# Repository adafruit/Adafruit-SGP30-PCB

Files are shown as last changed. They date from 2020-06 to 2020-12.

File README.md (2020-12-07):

## Adafruit SGP30 Air Quality Sensor PCB

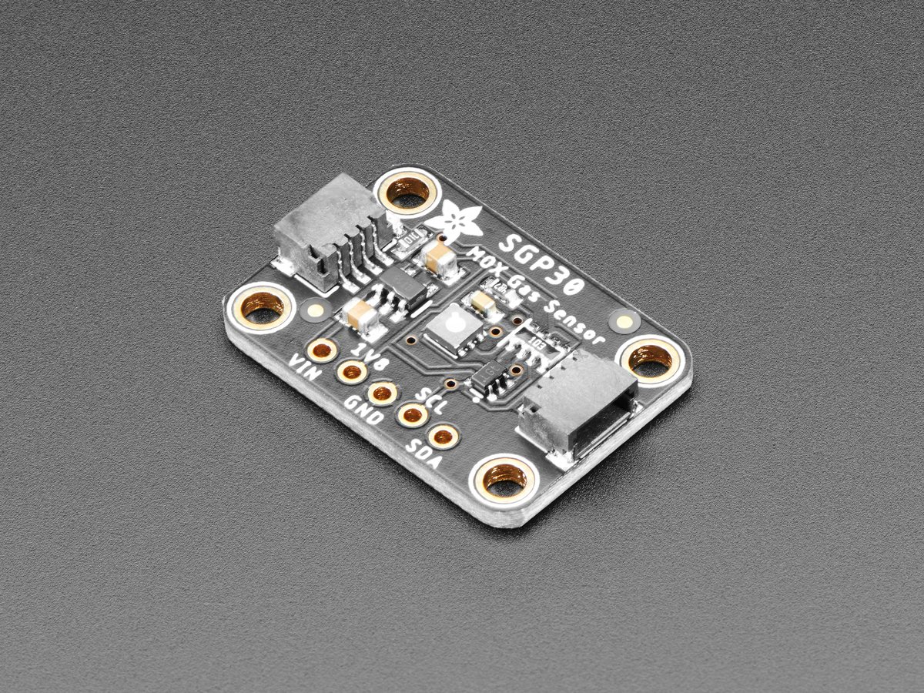
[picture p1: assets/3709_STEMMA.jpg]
<a href="http://www.adafruit.com/products/3709"><br/>
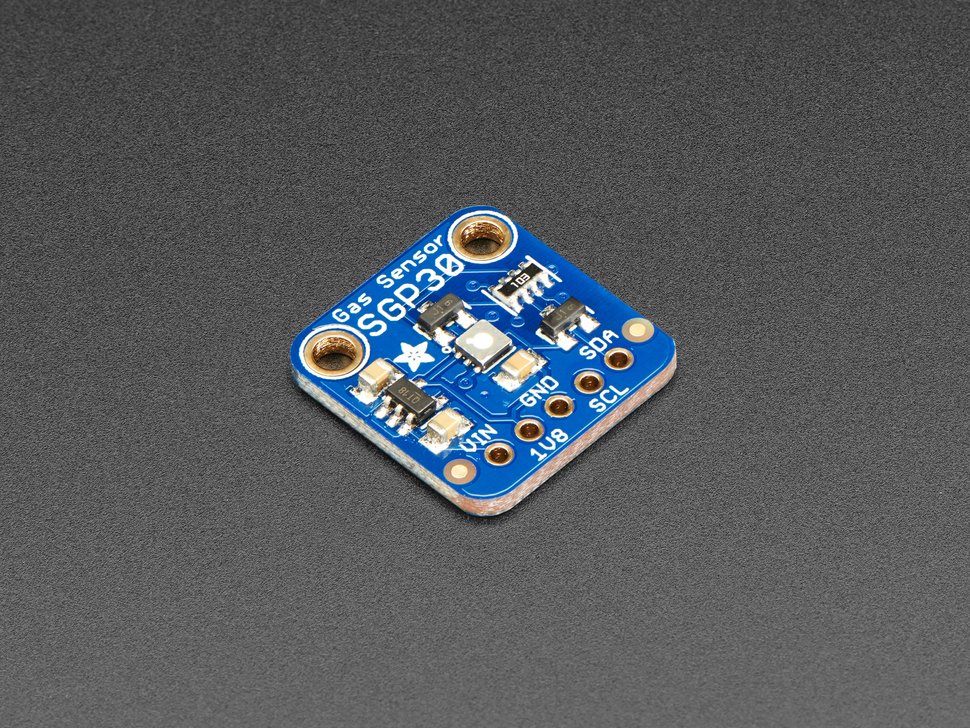
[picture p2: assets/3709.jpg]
<a href="http://www.adafruit.com/products/3709"><br/>
Click here to purchase one from the Adafruit shop</a>

PCB files for the Adafruit SGP30 Air Quality Sensor. 

Format is EagleCAD schematic and board layout
* https://www.adafruit.com/product/3709

### Description

Breathe easy with the SGP30 Multi-Pixel Gas Sensor, a fully integrated MOX gas sensor. This is a very fine air quality sensor from the sensor experts at Sensirion, with I2C interfacing and fully calibrated output signals with a typical accuracy of 15% within measured values. The SGP combines multiple metal-oxide sensing elements on one chip to provide more detailed air quality signals.

This is a gas sensor that can detect a wide range of Volatile Organic Compounds (VOCs) and H2 and is intended for indoor air quality monitoring. When connected to your microcontroller (running our library code) it will return a Total Volatile Organic Compound (TVOC) reading and an equivalent carbon dioxide reading (eCO2) over I2C.

The SGP30 has a 'standard' hot-plate MOX sensor, as well as a small microcontroller that controls power to the plate, reads the analog voltage, tracks the baseline calibration, calculates TVOC and eCO2 values, and provides an I2C interface to read from. Unlike the CCS811, this sensor does not require I2C clock stretching.

This part will measure eCO2 (equivalent calculated carbon-dioxide) concentration within a range of 400 to 60,000 parts per million (ppm), and TVOC (Total Volatile Organic Compound) concentration within a range of 0 to 60,000 parts per billion (ppb).

Please note, this sensor, like all VOC/gas sensors, has variability and to get precise measurements you will want to calibrate it against known sources! That said, for general environmental sensors, it will give you a good idea of trends and comparison. The SGP30 does have built in calibration capabilities, note that eCO2 is calculated based on H2 concentration, it is not a 'true' CO2 sensor for laboratory use.

Another nice element to this sensor is the ability to set humidity compensation for better accuracy. An external humidity sensor is required and then the RH% is written over I2C to the sensor, so it can better calculate the TVOC/eCO2 values.

Nice sensor right? So we made it easy for you to get right into your next project. The surface-mount sensor is soldered onto a custom made PCB in the STEMMA QT form factor, making them easy to interface with. The STEMMA QT connectors on either side are compatible with the SparkFun Qwiic I2C connectors. This allows you to make solderless connections between your development board and the SGP30 or to chain it with a wide range of other sensors and accessories using a compatible cable.

We’ve of course broken out all the pins to standard headers and added a 1.8V voltage regulator and level shifting so allow you to use it with either 3.3V or 5V systems such as the Raspberry Pi, or Metro M4 or Arduino Uno.

### License

Adafruit invests time and resources providing this open source design, please support Adafruit and open-source hardware by purchasing products from [Adafruit](https://www.adafruit.com)!

Designed by Kevin (KTOWN) Townsend for Adafruit Industries.

Creative Commons Attribution/Share-Alike, all text above must be included in any redistribution. 
See license.txt for additional details.

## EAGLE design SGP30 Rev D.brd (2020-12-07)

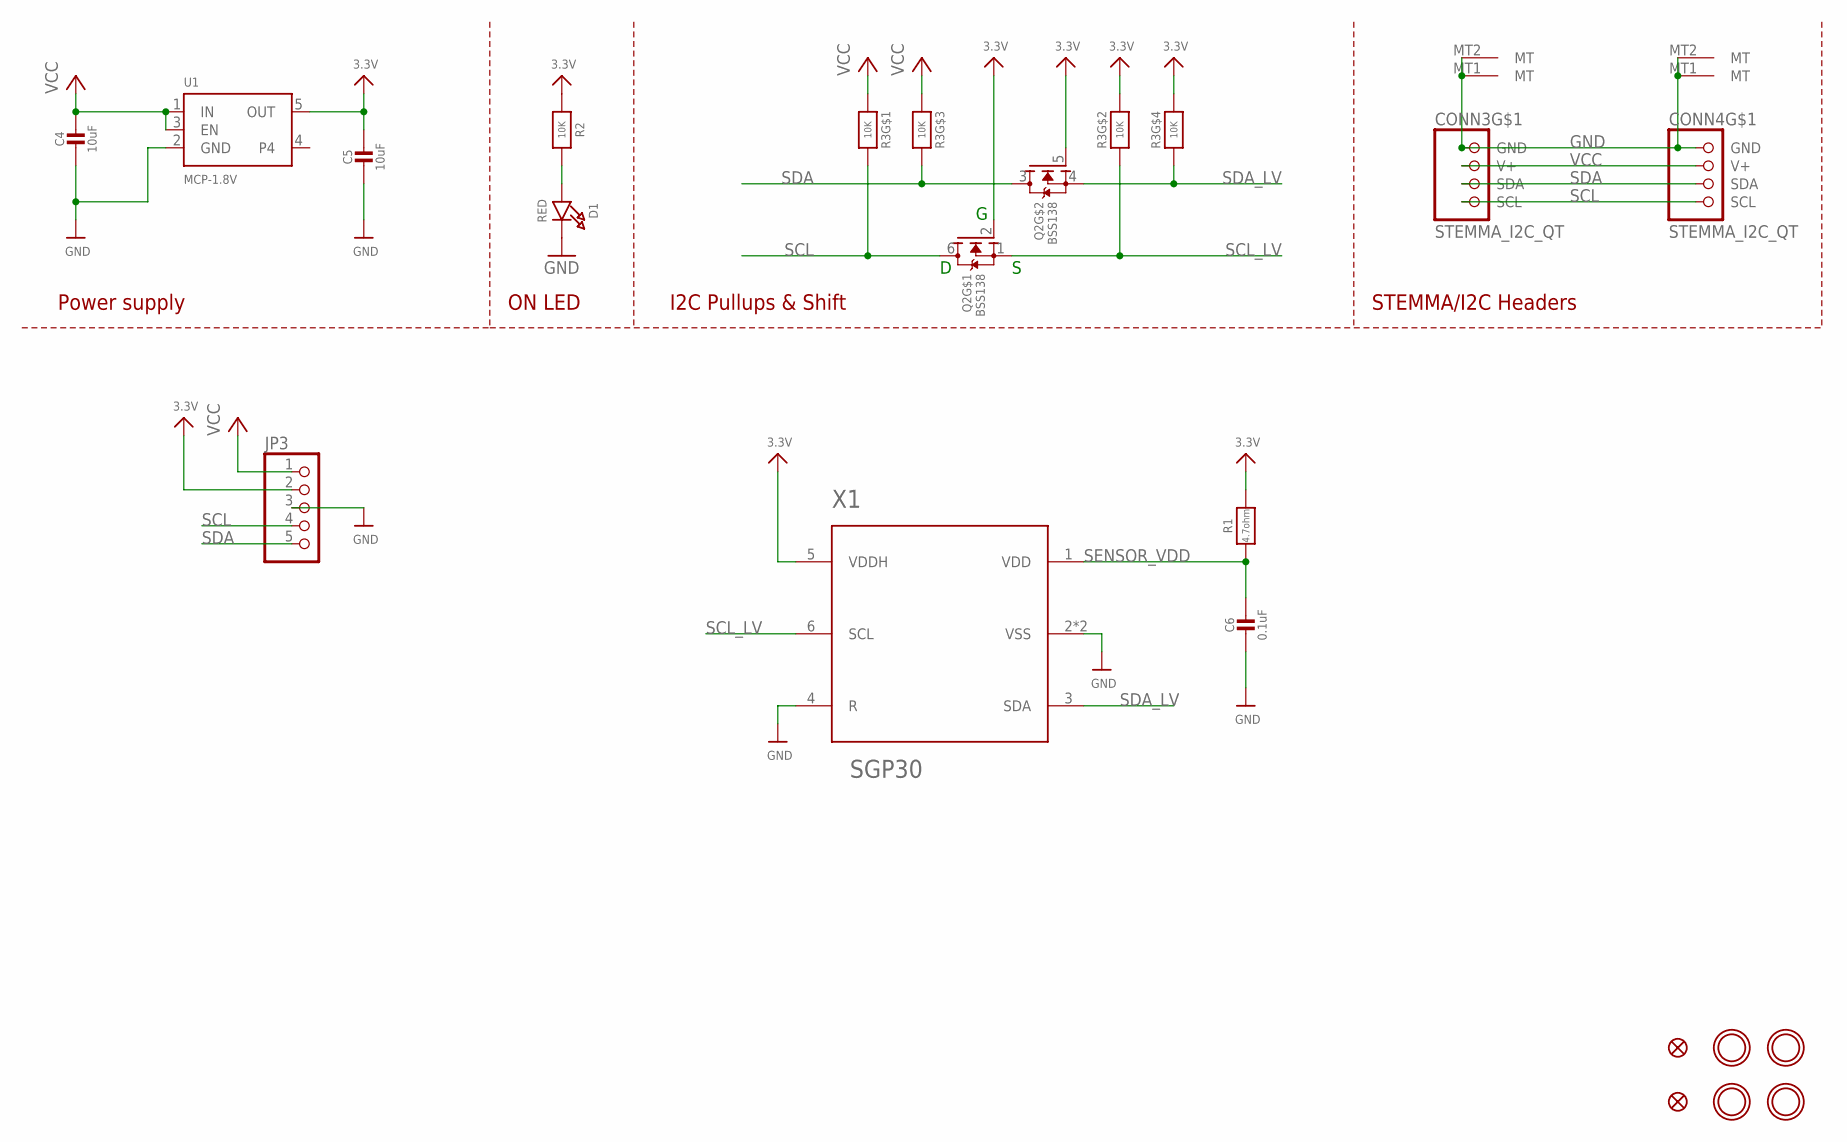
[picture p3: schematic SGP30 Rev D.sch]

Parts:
C4, C5: 10uF; 0805-NO
C6: 0.1uF; 0603-NO
CONN3, CONN4: STEMMA_I2C_QT; JST_SH4
D1: RED; CHIPLED_0603_NOOUTLINE
FID3, FID4: FIDUCIAL_1MM
JP3: HEADER-1X570MIL; 1X05_ROUND_70
Q2: BSS138; SOT363
R1: 4.7ohm; 0603-NO
R2: 10K; 0603-NO
R3: 10K; RESPACK_4X0603
U1: MCP-1.8V; SOT23-5
U$28, U$29, U$31, U$32: MOUNTINGHOLE2.5; MOUNTINGHOLE_2.5_PLATED
X1: SGP30

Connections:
3.3V: C5.1, JP3.2, Q2.2 (G), Q2.5 (G), R1.2, R2.1, R3.2 (1), R3.4 (1), U1.5 (OUT), X1.5 (VDDH)
GND: C4.2, C5.2, C6.2, CONN3.1 (GND), CONN3.MT1 (MT), CONN3.MT2 (MT), CONN4.1 (GND), CONN4.MT1 (MT), CONN4.MT2 (MT), D1.C, JP3.3, U1.2 (GND), X1.2 (VSS), X1.4 (R), X1.P$7 (VSS)
unnamed: D1.A, R2.2
SCL: CONN3.4 (SCL), CONN4.4 (SCL), JP3.4, Q2.6 (D), R3.8 (2)
SCL_LV: Q2.1 (S), R3.7 (2), X1.6 (SCL)
SDA: CONN3.3 (SDA), CONN4.3 (SDA), JP3.5, Q2.3 (D), R3.6 (2)
SDA_LV: Q2.4 (S), R3.5 (2), X1.3 (SDA)
SENSOR_VDD: C6.1, R1.1, X1.1 (VDD)
VCC: C4.1, CONN3.2 (V+), CONN4.2 (V+), JP3.1, R3.1, R3.3 (1), U1.1 (IN), U1.3 (EN)

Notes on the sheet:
I2C Pullups & Shift
STEMMA/I2C Headers
ON LED
Power supply

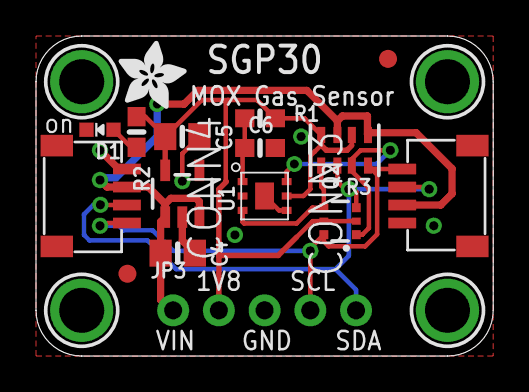
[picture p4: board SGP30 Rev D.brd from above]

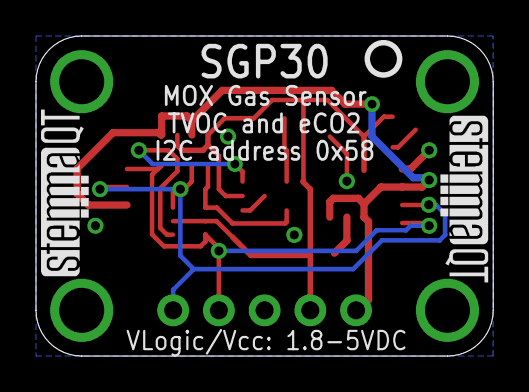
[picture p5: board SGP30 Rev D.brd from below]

Board: 2 copper layers, 25.4 x 17.8 mm, 23 parts (3 on the bottom side), 9 nets.

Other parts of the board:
U$34: ADAFRUIT_3.5MM
U$35: PCBFEAT-REV-040
U$36, U$37: STEMMAQT

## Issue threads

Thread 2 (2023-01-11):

Sensor's power pin still left labeled 3.3v

rpavlik, 2023-01-11:
Even though it's a 1.8V regulator :facepalm: My colleague looked at the power node name, I looked at the regulator part, and we disagreed on the voltage it got :D

Of course this doesn't affect the product, but it would be handy to fix in the schematics. I don't have eagle so can't fix them or you'd have a PR by now.

eschlenz, 2023-03-18:
+1 this was confusing for me too.

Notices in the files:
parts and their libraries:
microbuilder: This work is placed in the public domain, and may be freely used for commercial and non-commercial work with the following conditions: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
